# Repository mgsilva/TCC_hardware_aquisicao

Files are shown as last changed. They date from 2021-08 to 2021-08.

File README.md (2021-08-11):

# TCC - Hardware Aquisição
Layout da PCB do sistema de aquisição utilizado no Trabalho de Conclusão de Curso do CEFET-MG.

Tema: Projeto e implementação de uma plataforma IoT para monitoramento de motores de indução trifásicos.

Este hardware conta com um sensor de corrente, um filtro antialiasing, um conversor de nível e um ESP32.
O sistema é capaz de aquisitar sinais até 5Khz.

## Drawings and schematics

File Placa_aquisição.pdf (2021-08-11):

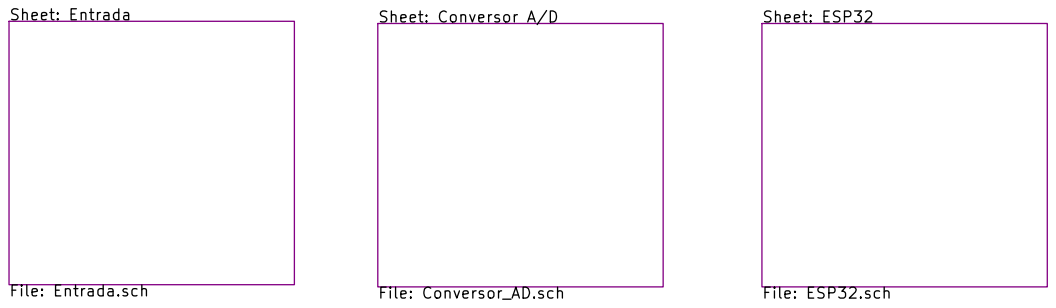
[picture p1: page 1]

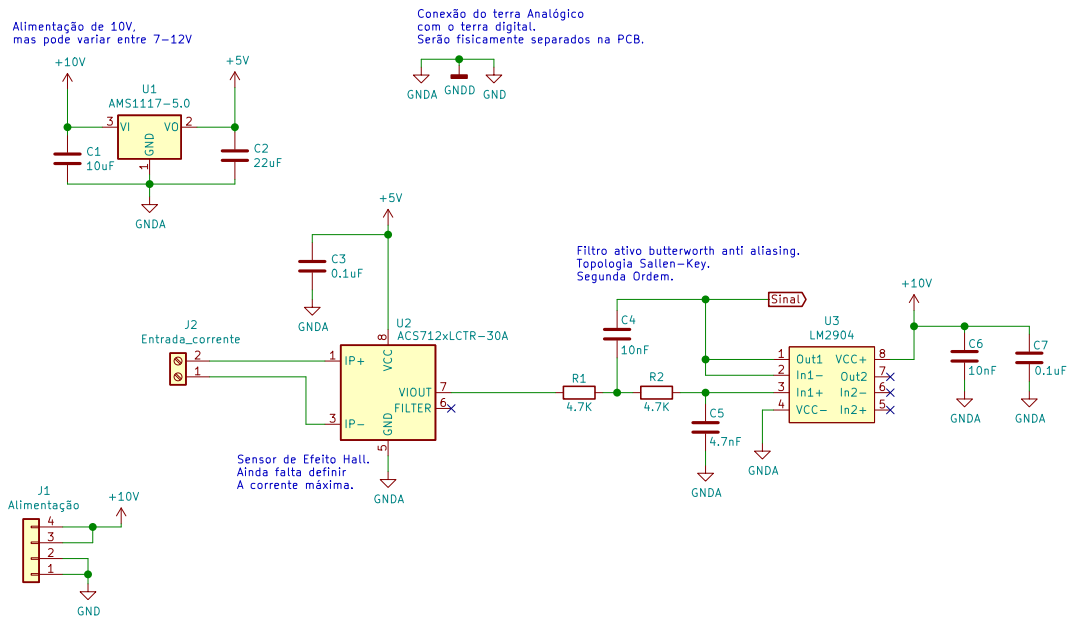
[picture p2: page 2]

10nF Sinal Conexão do terra Analógico
com o terra digital.
Serão fisicamente separados na PCB.
+5V GND

Alimentação de 10V,
mas pode variar entre 7-12V

Filtro ativo butterworth anti aliasing.
Topologia Sallen-Key.
Segunda Ordem.

Sensor de Efeito Hall. Ainda falta definir A corrente máxima.

Id: 2/4 Title: File: Entrada.sch Sheet: /Entrada/

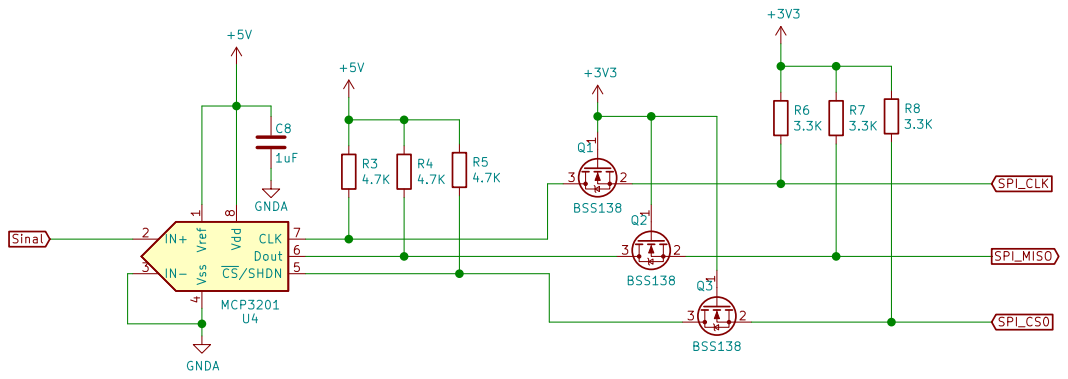
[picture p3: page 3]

File: Conversor_AD.sch Sheet: /Conversor A/D/
Id: 3/4 Title:

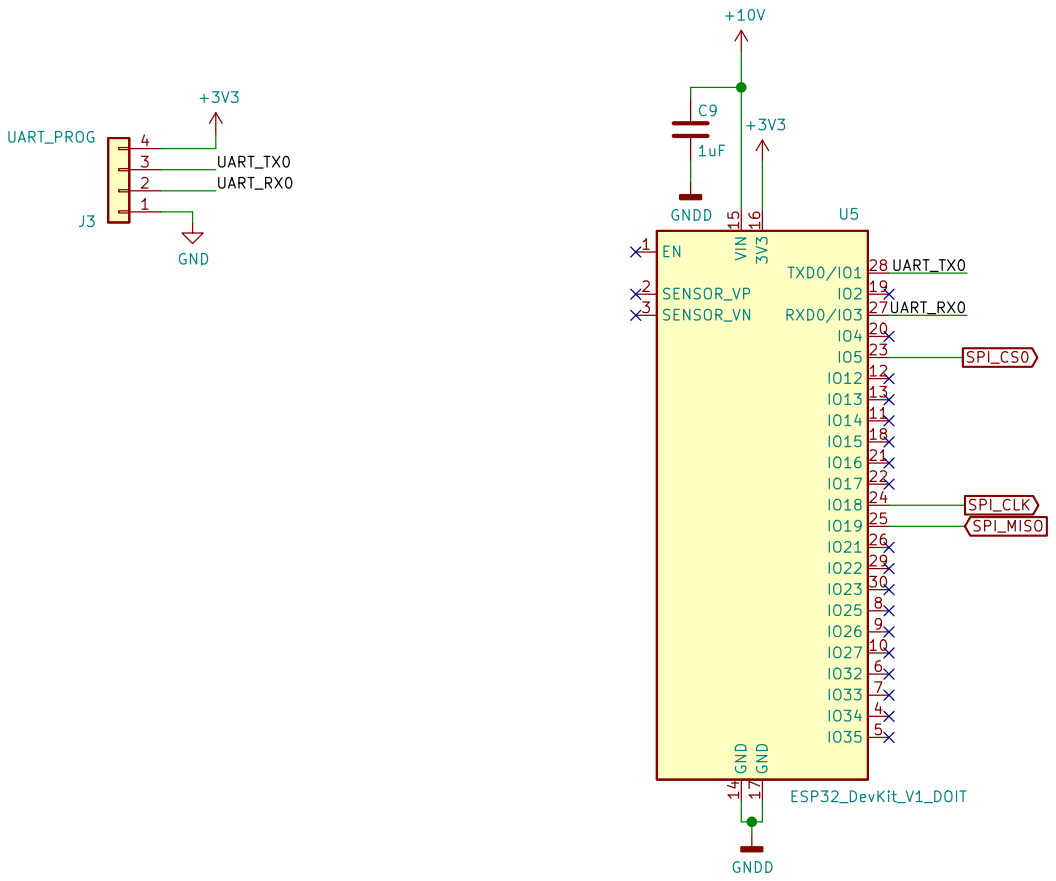
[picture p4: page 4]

Id: 4/4 Title: File: ESP32.sch Sheet: /ESP32/

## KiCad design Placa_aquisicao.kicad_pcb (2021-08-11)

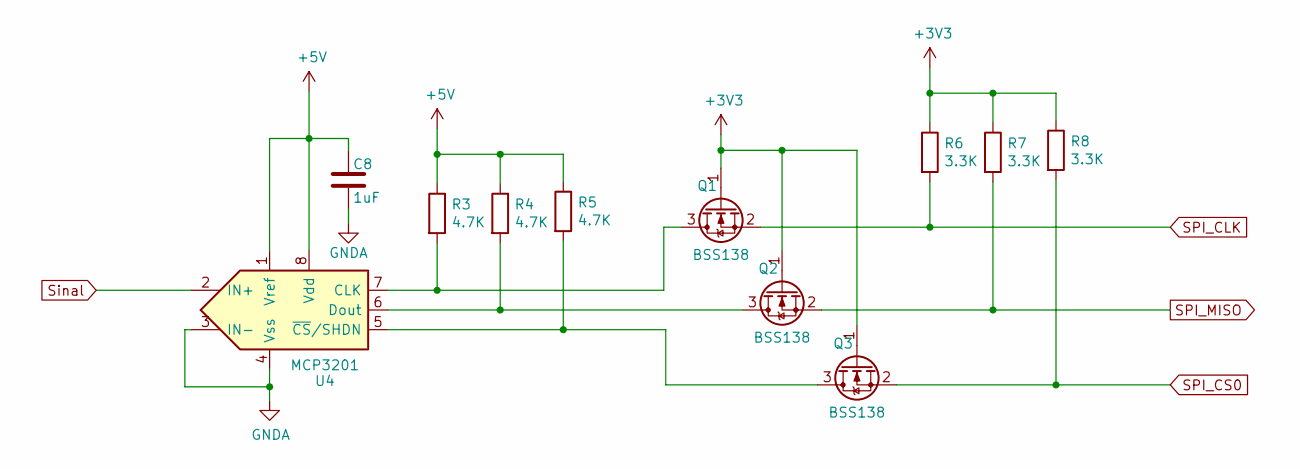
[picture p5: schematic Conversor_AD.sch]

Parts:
C8: 1uF; C_0805_2012Metric_Pad1.18x1.45mm_HandSolder
Q1, Q2, Q3: BSS138; SOT-23
R3, R4, R5: 4.7K; R_0805_2012Metric_Pad1.20x1.40mm_HandSolder
R6, R7, R8: 3.3K; R_0805_2012Metric_Pad1.20x1.40mm_HandSolder
U4: MCP3201; SOIC-8_3.9x4.9mm_P1.27mm

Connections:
+3V3: Q1.1 (G), Q2.1 (G), Q3.1 (G), R6.1, R7.1, R8.1; also elsewhere on the board
+5V: C8.1, R3.1, R4.1, R5.1, U4.1 (Vref), U4.8 (Vdd); also elsewhere on the board
GND: C8.2, U4.3 (IN-), U4.4 (Vss); also elsewhere on the board
unnamed: Q1.3 (D), R3.2, U4.7 (CLK)
unnamed: Q2.3 (D), R4.2, U4.6 (Dout)
unnamed: Q3.3 (D), R5.2, U4.5 (~CS~/SHDN)
SPI_CLK: Q1.2 (S), R6.2; also elsewhere on the board
SPI_CS0: Q3.2 (S), R8.2; also elsewhere on the board
SPI_MISO: Q2.2 (S), R7.2; also elsewhere on the board
Sinal: U4.2 (IN+); also elsewhere on the board

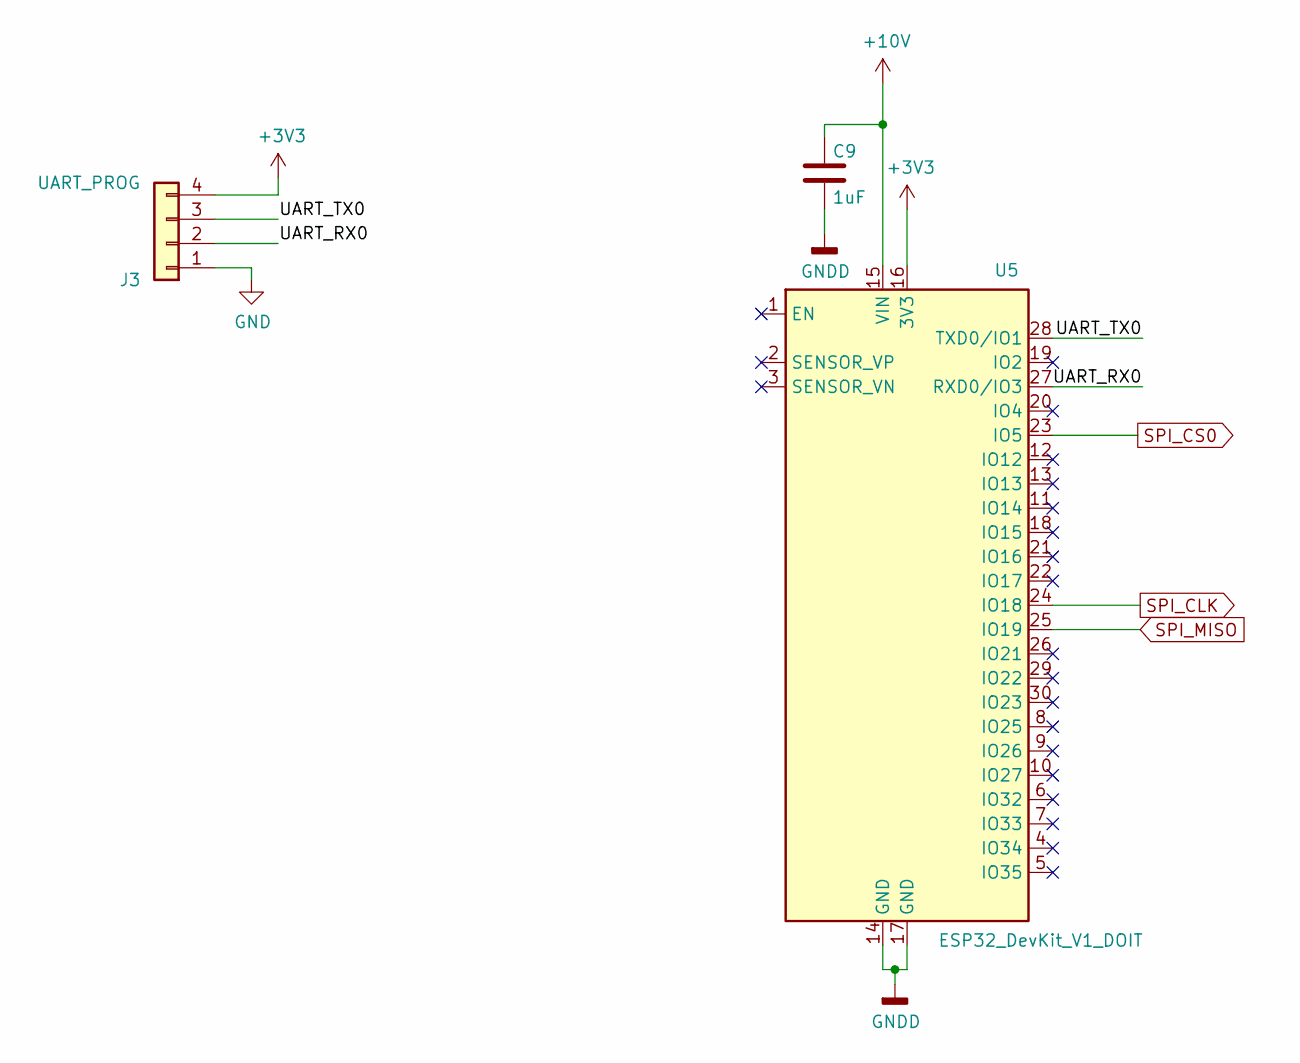
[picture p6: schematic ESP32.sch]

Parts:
C9: 1uF; C_0805_2012Metric_Pad1.18x1.45mm_HandSolder
J3: UART_PROG; Molex_KK-254_AE-6410-04A_1x04_P2.54mm_Vertical
U5: ESP32_DevKit_V1_DOIT; esp32_devkit_v1_doit

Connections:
+3V3: J3.4, U5.16 (3V3); also elsewhere on the board
+10V: C9.1, U5.15 (VIN); also elsewhere on the board
/ESP32/UART_RX0: J3.2, U5.27 (RXD0/IO3)
/ESP32/UART_TX0: J3.3, U5.28 (TXD0/IO1)
GND: C9.2, J3.1, U5.14 (GND), U5.17 (GND); also elsewhere on the board
SPI_CLK: U5.24 (IO18); also elsewhere on the board
SPI_CS0: U5.23 (IO5); also elsewhere on the board
SPI_MISO: U5.25 (IO19); also elsewhere on the board

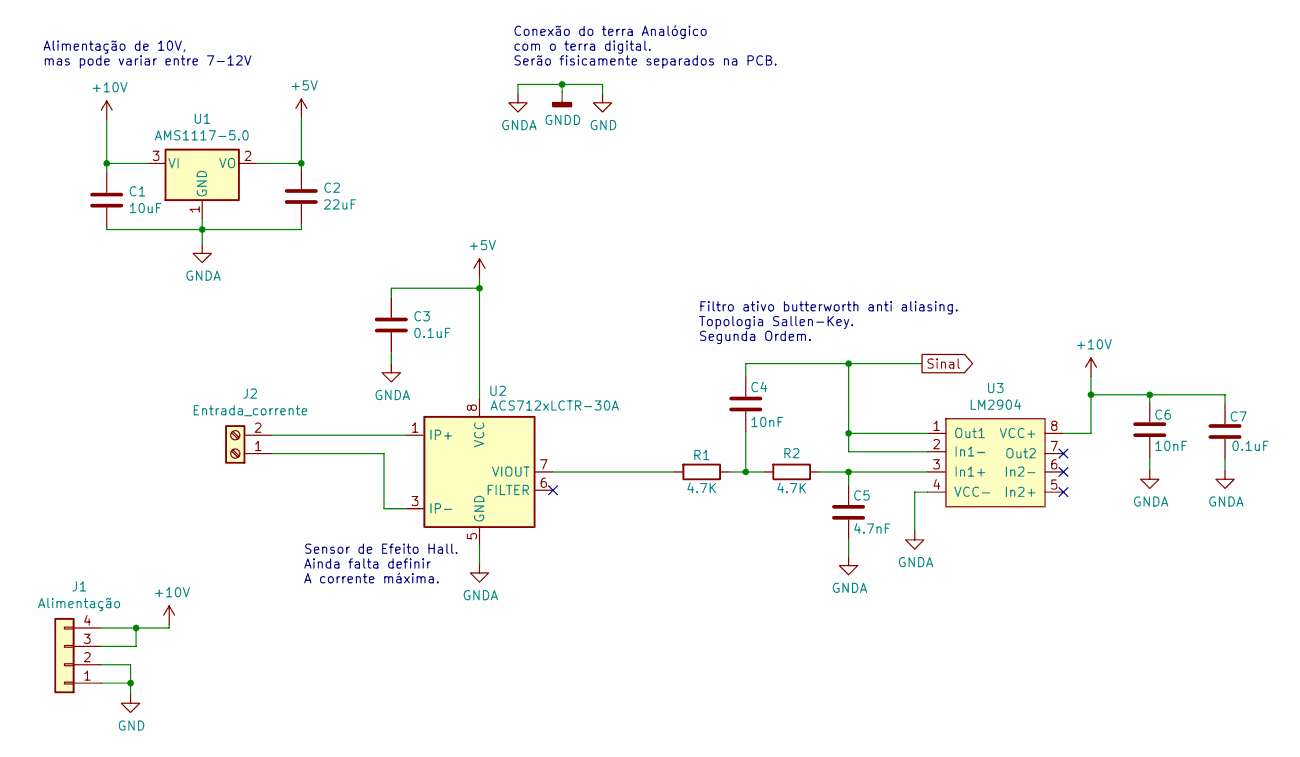
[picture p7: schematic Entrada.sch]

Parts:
C1: 10uF; C_0805_2012Metric_Pad1.18x1.45mm_HandSolder
C2: 22uF; C_1206_3216Metric_Pad1.33x1.80mm_HandSolder
C3, C7: 0.1uF; C_0805_2012Metric_Pad1.18x1.45mm_HandSolder
C4, C6: 10nF; C_0805_2012Metric_Pad1.18x1.45mm_HandSolder
C5: 4.7nF; C_0805_2012Metric_Pad1.18x1.45mm_HandSolder
J1: Alimentação; Molex_KK-254_AE-6410-04A_1x04_P2.54mm_Vertical
J2: Entrada_corrente; TerminalBlock_Phoenix_MKDS-1,5-2_1x02_P5.00mm_Horizontal
R1, R2: 4.7K; R_0805_2012Metric_Pad1.20x1.40mm_HandSolder
U1: AMS1117-5.0; SOT-223-3_TabPin2
U2: ACS712xLCTR-30A; SOIC-8_3.9x4.9mm_P1.27mm
U3: LM2904; SO-8_3.9x4.9mm_P1.27mm

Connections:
+5V: C2.1, C3.1, U1.2 (VO), U2.8 (VCC); also elsewhere on the board
+10V: C1.1, C6.1, C7.1, J1.3, J1.4, U1.3 (VI), U3.8 (VCC+); also elsewhere on the board
GND: C1.2, C2.2, C3.2, C5.2, C6.2, C7.2, J1.1, J1.2, U1.1 (GND), U2.5 (GND), U3.4 (VCC-); also elsewhere on the board
unnamed: C4.2, R1.1, R2.2
unnamed: C5.1, R2.1, U3.3 (In1+)
unnamed: J2.1, U2.3 (IP-), U2.4 (IP-)
unnamed: J2.2, U2.1 (IP+), U2.2 (IP+)
unnamed: R1.2, U2.7 (VIOUT)
Sinal: C4.1, U3.1 (Out1), U3.2 (In1-); also elsewhere on the board

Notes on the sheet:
Conexão do terra Analógico com o terra digital. Serão fisicamente separados na PCB.
Filtro ativo butterworth anti aliasing. Topologia Sallen-Key. Segunda Ordem.
Alimentação de 10V, mas pode variar entre 7-12V
Sensor de Efeito Hall. Ainda falta definir A corrente máxima.

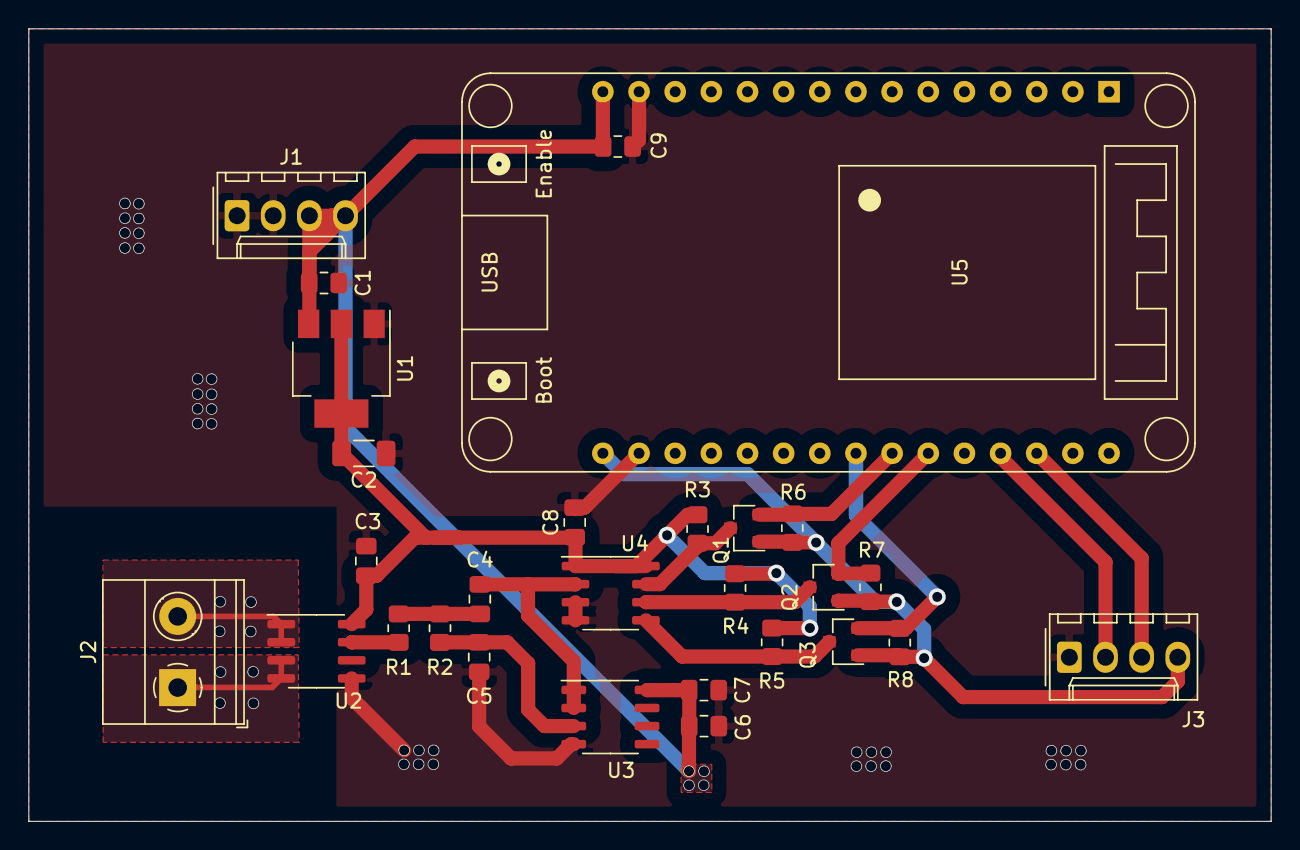
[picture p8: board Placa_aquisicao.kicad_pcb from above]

Board: 2 copper layers, 87.3 x 55.7 mm, 28 parts (0 on the bottom side), 18 nets.
